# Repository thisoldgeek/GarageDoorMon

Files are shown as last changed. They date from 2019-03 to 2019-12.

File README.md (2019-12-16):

# **GarageDoorMon**
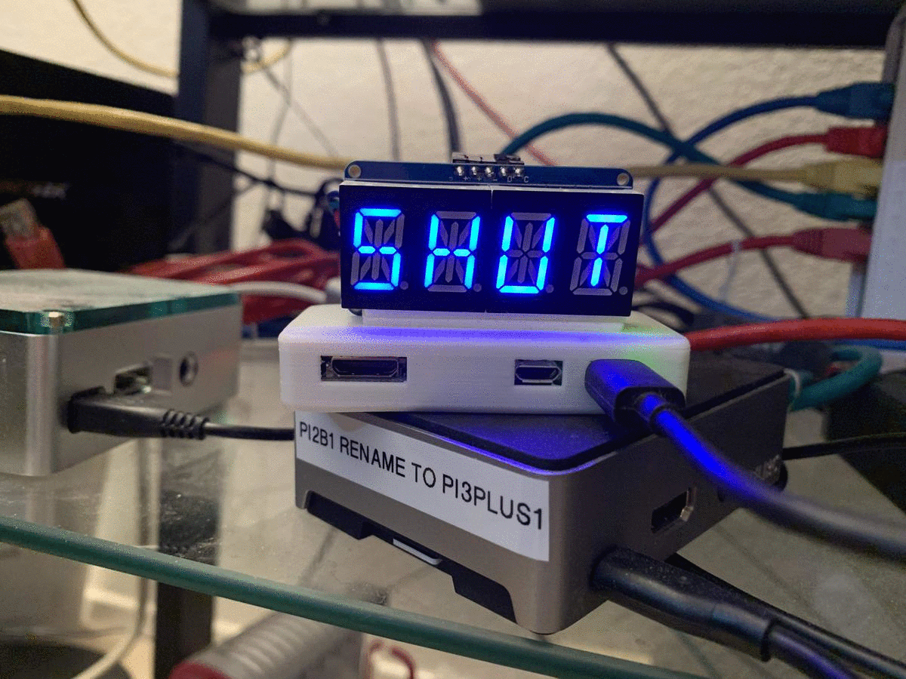
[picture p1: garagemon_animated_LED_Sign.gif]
GarageDoorMon Garage Door Monitor

 
## *Description:*
An Adafruit Feather Huzzah that posts garage door open/closed status to adafruit.io.
The adafruit.io MQTT feed is subscribed to by a raspberry pi zero w and the status
(SHUT/OPEN) is displayed on a 4-digit alphanumeric display connected to the pi zero w.

This is basically the project from: https://learn.adafruit.com/using-ifttt-with-adafruit-io/overview,
with a few tweaks and add-ons:
* GarageDoorMon doesn't use a battery, it's powered by a 5V adapter; requires mains power source, long wire
* Logic is reversed, a '1' is sent to adafruit.io when the garage door is open, '0' when closed(SHUT)
* Added: raspberry pi zero w runs a system service to monitor the door status, shows on 4-digit display
* IFTTT is not required! Of course, you can use it if you like. 
This version uses MQTT subscribe directly from adafruit.io feed, via python cllient code.

See the posting at:

http://thisoldgeek.blogspot.com/2019/03/garage-door-monitor.html

## *Required Software:*
Requires install of the library from: https://github.com/adafruit/Adafruit_Python_LED_Backpack
See the README on that git for instructions

Also requires sign-up/set-up for adafruit.io; follow the instructions in:
https://learn.adafruit.com/using-ifttt-with-adafruit-io/adafruit-io-setup-uniontownlabs

If you use this MQTT version, follow the instructions to install the adafruit.io python client library:
https://learn.adafruit.com/welcome-to-adafruit-io/client-library

Also - review the MQTT documentation:
https://learn.adafruit.com/welcome-to-adafruit-io/mqtt-api-documentation-2

Bonus: Modified mosquitto.conf. Use this to set up bridging from adafruit.io to a local MQTT broker. 
This is useful if you already have your own broker.

## *Required Hardware:*
* Adafruit Feather Huzzah
* Wire - used 18 AWG thermostat wire
* Magnetic Door Switch, Normally Open (NO)
* External resistor pullup network
* Adafruit 4 digit 14-segment alphanumeric display, for status
* Raspberry Pi Zero W

## *Fabrication:*
* Optional Adafruit Feather Huzzah 3D printed case; M2 screws (https://www.thingiverse.com/thing:2209964)
* Optional Adafruit 3D printed case for raspberry pi zero W (https://www.thingiverse.com/thing:1165227)
* Double-side foam tape to fasten alphanumeric display to raspberry pi case

## UPDATE 12/15/2019:
Added an optional buzzer on the display that beeps three times when OPEN state is first received.
The buzzer will not sound during "quiet_time" set in the program, default to start 21:00, end 08:00

The new python script is named garage_mon_buzzer.py. Download this script and copy it like so:

cd ~/GarageDoorMon
sudo cp garage_mon_buzzer.py garage_mon.py 
Update your username and AIO Key after copying over to garage_mon.py

Add the library:
sudo apt-get install python-rpi.gpio python3-rpi.gpio 

Use an active piezo buzzer, connect female-to-female jumpers:
* +/positive (usually longer pin) to BCM pin 17
* -/negative (shorter pin) to GND

and restart the service:
sudo systemctl restart gmon

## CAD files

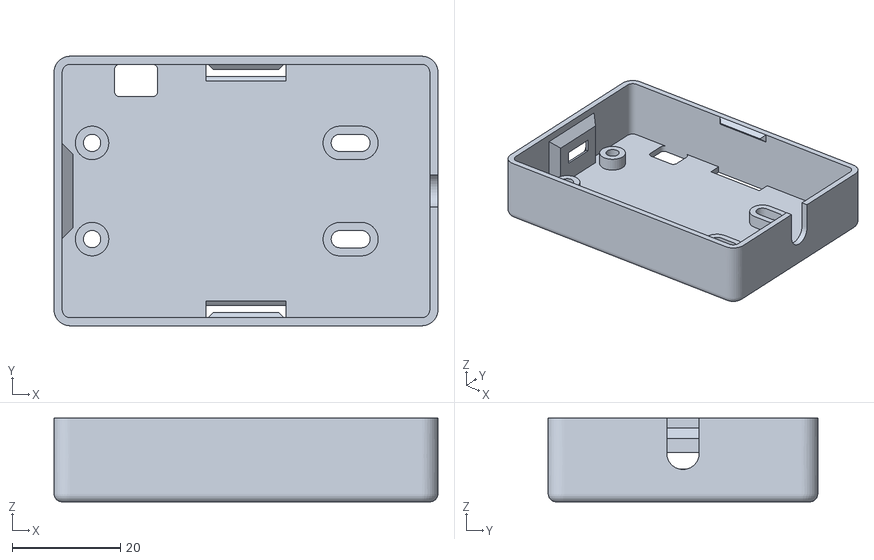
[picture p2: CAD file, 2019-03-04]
feather-case.stl
71.0 x 49.9 x 15.5

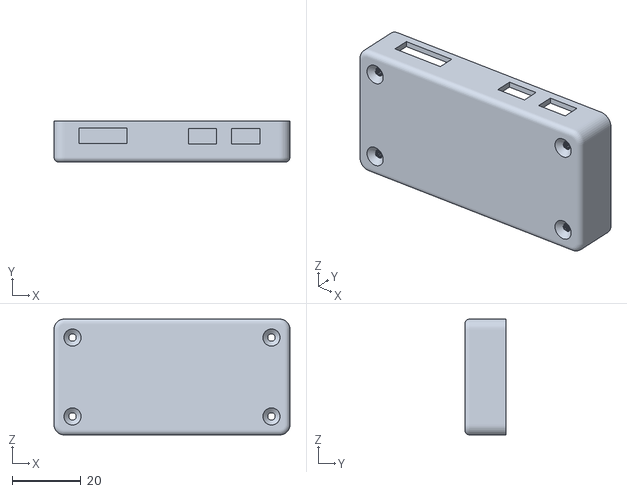
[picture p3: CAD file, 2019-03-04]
pizero-scaseholes.stl
68.8 x 12.0 x 33.8

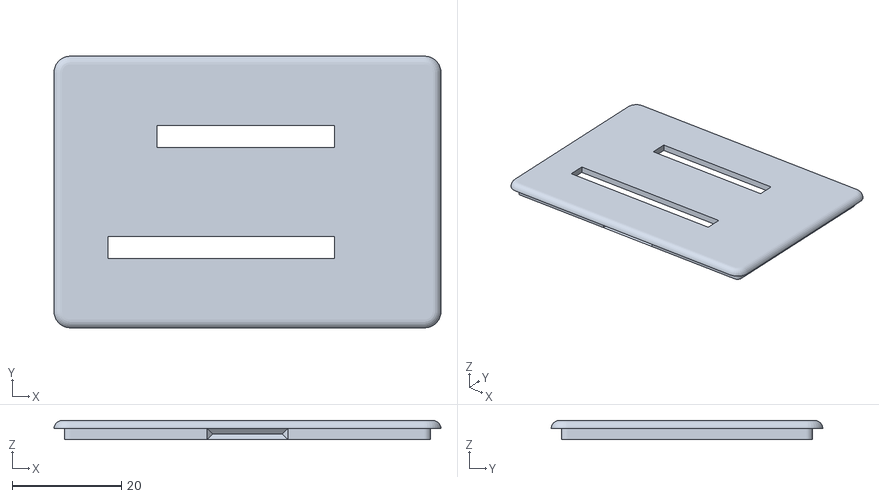
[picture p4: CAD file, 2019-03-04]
feather-top-headers.stl
71.0 x 49.9 x 3.50

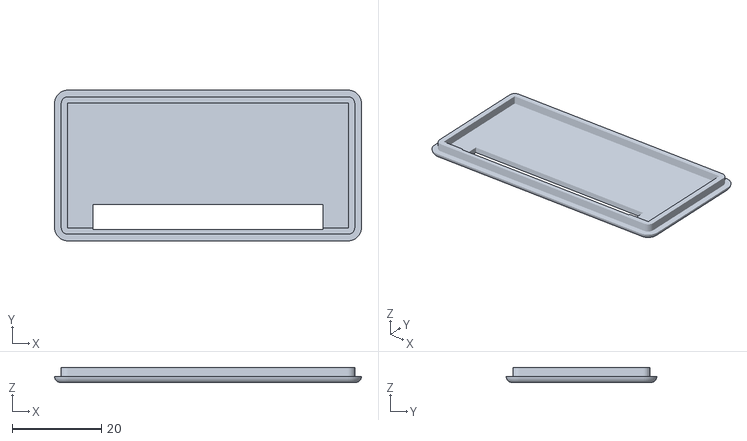
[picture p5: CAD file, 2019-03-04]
pizero-scover.stl
68.8 x 33.8 x 3.40

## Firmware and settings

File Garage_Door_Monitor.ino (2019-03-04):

// Adafruit IO IFTTT Door Detector
// 
// Learn Guide: https://learn.adafruit.com/using-ifttt-with-adafruit-io
//
// Adafruit invests time and resources providing this open source code.
// Please support Adafruit and open source hardware by purchasing
// products from Adafruit!
//
// Written by Todd Treece for Adafruit Industries
// Copyright (c) 2018 Adafruit Industries
// Licensed under the MIT license.
//
// All text above must be included in any redistribution.

/************************** Configuration ***********************************/

// edit the config.h tab and enter your Adafruit IO credentials
// and any additional configuration needed for WiFi, cellular,
// or ethernet clients.
#include "config.h"

/************************ Example Starts Here *******************************/

// door gpio pin
#define DOOR 13
// Variables to test change in state
int curr_door;
int prev_door;
      

AdafruitIO_Feed *door = io.feed("GarageDoor");

void setup() {

  // start the serial connection
  Serial.begin(115200);

  while (!Serial);
  Serial.println("Adafruit IO Garage Door Detector");

  /// connect to io.adafruit.com
  io.connect();

  
  // wait for a connection
  while(io.status() < AIO_CONNECTED) {
    Serial.print(".");
    delay(500);
  }

   // we are connected
  Serial.println();
  Serial.println(io.statusText());
  
  pinMode(DOOR, INPUT_PULLUP);  // internal pullup will be HIGH when magnetic switch is OPEN, LOW when CLOSED

   // if prev_door = curr_door do nothing; only send changed state

}  

void loop() {
// io.run(); is required for all sketches.
  // it should always be present at the top of your loop
  // function. it keeps the client connected to
  // io.adafruit.com, and processes any incoming data.
  io.run();
  
 // Magnetic contact switch is closed when garage door is open - registers as LOW

   curr_door = digitalRead(DOOR);
  
    if(curr_door != prev_door)
   {
    prev_door = curr_door;    
  
    
   if(curr_door == LOW) {
    Serial.println("Door IS open");
    // the switch is CLOSED/LOW when the garage door is OPEN
    door->save("OPEN");  
    }
    else {
    // the switch is OPEN/HIGH when the garage door is SHUT
    Serial.println("Door is closed!");
    door->save("SHUT"); 
    }
   }

  // Adafruit IO is rate limited for publishing, so a delay is required in
  // between feed->save events. In this example, we will wait three seconds
  // (1000 milliseconds == 1 second) during each loop.
  delay(3000);

   
}   

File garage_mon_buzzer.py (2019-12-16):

#!/usr/bin/env python3

# Example of using the MQTT client class to subscribe to and publish feed values.
# Author: Tony DiCola

# Import standard python modules.
import random
import sys
import time
import datetime
import RPi.GPIO as GPIO

#Select GPIO mode
GPIO.setmode(GPIO.BCM)
#Set buzzer - pin 17 as output
buzzer=17
GPIO.setup(buzzer,GPIO.OUT)
GPIO.output(buzzer,GPIO.LOW)  # Set buzzer off to start

alert = 0 # If =1 then buzzer function

# Import Adafruit IO MQTT client.
from Adafruit_IO import MQTTClient

from Adafruit_LED_Backpack import AlphaNum4

# Create display instance on default I2C address (0x70) and bus number.
display = AlphaNum4.AlphaNum4()

# Initialize the display. Must be called once before using the display.
display.begin()
display.set_brightness(2)

myText =  "STRT"

# Set to your Adafruit IO key.
# Remember, your key is a secret,
# so make sure not to publish it when you publish this code!
ADAFRUIT_IO_KEY = '********************************'
# Set to your Adafruit IO username.
# (go to https://accounts.adafruit.com to find your username)
ADAFRUIT_IO_USERNAME = '**********'

# Quiet Time: no alert actions will take place
quiet_start = 21			# quiet time starts at this hour, using 24hr style
quiet_end = 9				# quiet time ends at this hour

# DO NOT CHANGE program variable default that follows: quiet_state
# Program toggles to indicate if alerts will activate ("True") or be quiet ("False")
# This assumes you are running this program BEFORE quiet_start time
quiet_state = False

def quiet_time():
    #global quiet_start	# start time for quiet	
    #global quiet_end	# end time for quiet
    global quiet_state	# quiet True/False
	
    now = datetime.datetime.now()
    print(now)
    t = now.hour	# will be in 24hr format
		
    if quiet_state is False:
        if t >= quiet_start:
           quiet_state = True

        if quiet_state is True and t <= 12:
           if t >= quiet_end:
              quiet_state = False 

    return(quiet_state)


def beep():
    global alert
    global buzzer

    for i in range(3):
        GPIO.output(buzzer,GPIO.HIGH)
        #print ("Beep")
        time.sleep(0.5) # Delay in seconds
        GPIO.output(buzzer,GPIO.LOW)
        #print ("No Beep")
        time.sleep(0.5)
    alert = 0

# Define callback functions which will be called when certain events happen.
def connected(client):
    # Connected function will be called when the client is connected to Adafruit IO.
    # This is a good place to subscribe to feed changes.  The client parameter
    # passed to this function is the Adafruit IO MQTT client so you can make
    # calls against it easily.
    print('Connected to Adafruit IO!  Listening for GarageDoor changes...')
    # Subscribe to changes on a feed named DemoFeed.
    client.subscribe('GarageDoor')

def disconnected(client):
    # Disconnected function will be called when the client disconnects.
    print('Disconnected from Adafruit IO!')
    sys.exit(1)

def message(client, feed_id, payload):
    global myText
    # Message function will be called when a subscribed feed has a new value.
    # The feed_id parameter identifies the feed, and the payload parameter has
    # the new value.
    print('Feed {0} received new value: {1}'.format(feed_id, payload))
    # if payload == '1':
    #   myText = "OPEN"
    #elif payload == '0':
    #   myText = "SHUT"
    
    myText = payload;

# Create an MQTT client instance.
client = MQTTClient(ADAFRUIT_IO_USERNAME, ADAFRUIT_IO_KEY)

# Setup the callback functions defined above.
client.on_connect    = connected
client.on_disconnect = disconnected
client.on_message    = message

# Connect to the Adafruit IO server.
client.connect()

# Now the program needs to use a client loop function to ensure messages are
# sent and received.  There are a few options for driving the message loop,
# depending on what your program needs to do.

# The first option is to run a thread in the background so you can continue
# doing things in your program.
client.loop_background()

pos = 0

# Now send new values every 10 seconds.
print('Publishing a new message every 10 seconds (press Ctrl-C to quit)...')
while True:
    #value = random.randint(0, 100)
    #print('Publishing {0} to DemoFeed.'.format(value))
    #client.publish('GarageDoor', value)
    # Clear the display buffer.
    display.clear()
    # Print a 4 character string to the display buffer.
    display.print_str(myText[pos:pos+4])
    # Write the display buffer to the hardware.  This must be called to
    # update the actual display LEDs.
    display.write_display()
    # Increment position. Wrap back to 0 when the end is reached.
    pos += 1
    if pos > len(myText)-4:
        pos = 0
    if myText == "SHUT":
       alert = 1
    if myText == "OPEN" and alert == 1:
       if quiet_time() == False:
            beep()
    time.sleep(10)

# Another option is to pump the message loop yourself by periodically calling
# the client loop function.  Notice how the loop below changes to call loop
# continuously while still sending a new message every 10 seconds.  This is a
# good option if you don't want to or can't have a thread pumping the message
# loop in the background.
#last = 0
#print('Publishing a new message every 10 seconds (press Ctrl-C to quit)...')
#while True:
#   # Explicitly pump the message loop.
#   client.loop()
#   # Send a new message every 10 seconds.
#   if (time.time() - last) >= 10.0:
#       value = random.randint(0, 100)
#       print('Publishing {0} to DemoFeed.'.format(value))
#       client.publish('DemoFeed', value)
#       last = time.time()

# The last option is to just call loop_blocking.  This will run a message loop
# forever, so your program will not get past the loop_blocking call.  This is
# good for simple programs which only listen to events.  For more complex programs
# you probably need to have a background thread loop or explicit message loop like
# the two previous examples above.
#client.loop_blocking()

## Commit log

2019-12-16 added optional buzzer for OPEN
    [garage_mon_buzzer.py]
2019-12-16 add buzzer quiet_time function
    [garage_mon_buzzer.py]
